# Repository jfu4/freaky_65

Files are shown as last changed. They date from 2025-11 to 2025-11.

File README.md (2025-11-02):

# freaky_65
This is my first mechanical keybaord PCB.

Specifications:
- 65 % Layout
- USB-C
- STM32MCU
- Rotary encoder
- RGB Lighting
- Custom key mapping
- Modular mounting holes

Avatar Fire Nation Build:  


Japanese Black and White Office Build:  


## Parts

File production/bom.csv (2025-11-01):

Designator | Footprint | Quantity | Value | LCSC Part #
BOOT1, RST1 | SW_SPST_TL3342 | 2 | SW_SPST | C318884
C1, C3, C4, C5, C6, C7, C8 | 402 | 7 | 100nF | C1525
C10, C9 | 402 | 2 | 1uF | C52923
C11, C12, C13, C14, C15, C16, C17, C18, C19, C20, C21, C22, C23, C24, C25, C26 | 402 | 16 | 0.1 uF | C1525
C2 | 603 | 1 | 10uF | C15525
D1, D10, D11, D12, D13, D14, D15, D16, D17, D18, D19, D2, D20, D21, D22, D23, D24, D25, D26, D27, D28, D29, D3, D30, D31, D32, D33, D34, D35, D36, D37, D38, D39, D4, D40, D41, D42, D43, D44, D45, D46, D47, D48, D49, D5, D50, D51, D52, D53, D54, D55, D56, D57, D58, D59, D6, D60, D61, D62, D63, D64, D65, D66, D67, D68, D7, D8, D9 | D_SOD-123 | 68 | D_Small | C81598
D69, D70, D71, D72, D73, D74, D75, D76, D77, D78, D79, D80, D81, D82 | LED_WS2812B_PLCC4_5.0x5.0mm_P3.2mm | 14 | WS2812B | C2843785
F1 | 1206 | 1 | 500mA | C135341
J1 | USB_C_Receptacle_HRO_TYPE-C-31-M-12 | 1 | USB_C_Receptacle_USB2.0 | C165948
R1, R2, R3, R4 | 402 | 4 | 5.1k | C25905
R7, R8 | 603 | 2 | 5.1k
SW2 | ROT_Alps_EC11E-Switch | 1 | RotaryEncoder_Switch | C202365
U1 | LQFP-48_7x7mm_P0.5mm | 1 | STM32F072CBT6
U2 | SOT-143 | 1 | PRTR5V0U2X | C2827688
U3 | SOT-23 | 1 | XC6206PxxxMR-Regulator_Linear | C5446
U4 | SOT-363_SC-70-6_Handsoldering | 1 | TXB0101 | C324081

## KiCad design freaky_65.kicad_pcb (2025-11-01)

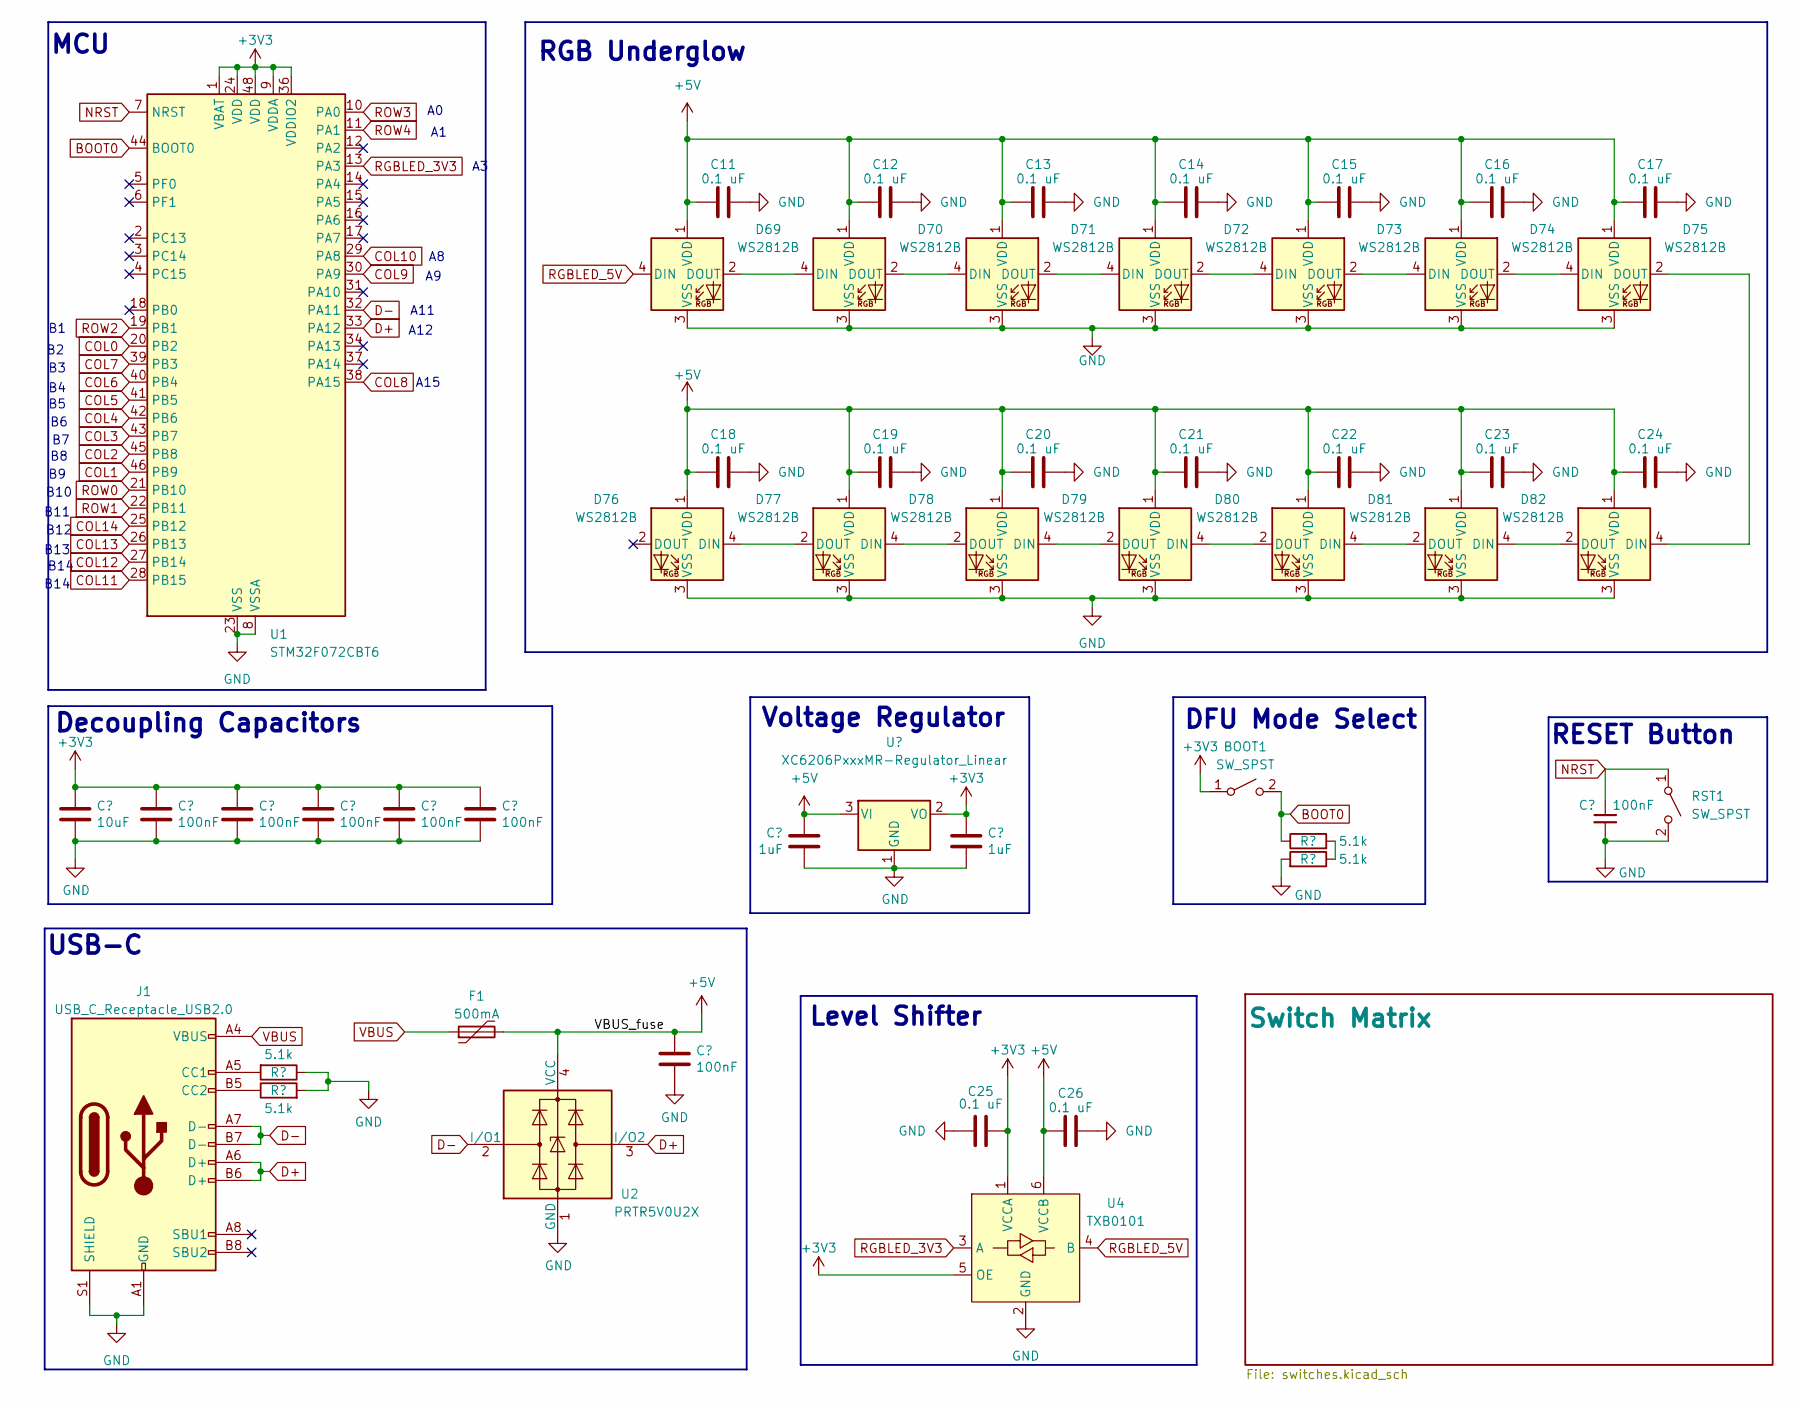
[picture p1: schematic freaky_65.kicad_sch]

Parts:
BOOT1: SW_SPST; SW_SPST_TL3342
C1, C3, C4, C5, C6, C7, C8: 100nF; C_0402_1005Metric; LCSC C307331
C2: 10uF; C_0603_1608Metric; LCSC C307331
C9, C10: 1uF; C_0402_1005Metric; LCSC C307331
C11, C12, C13, C14, C15, C16, C17, C18, C19, C20, C21, C22, C23, C24, C25, C26: 0.1 uF; C_0402_1005Metric_Pad0.74x0.62mm_HandSolder
D69, D70, D71, D72, D73, D74, D75, D76, D77, D78, D79, D80, D81, D82: WS2812B; LED_WS2812B_PLCC4_5.0x5.0mm_P3.2mm
F1: 500mA; Fuse_1206_3216Metric; LCSC C135341
J1: USB_C_Receptacle_USB2.0; USB_C_Receptacle_HRO_TYPE-C-31-M-12; JlcRotOffset 180
R1, R2, R3, R4: 5.1k; R_0402_1005Metric
RST1: SW_SPST; SW_SPST_TL3342
U1: STM32F072CBT6; LQFP-48_7x7mm_P0.5mm; JlcRotOffset 90
U2: PRTR5V0U2X; SOT-143; LCSC C2827688
U3: XC6206PxxxMR-Regulator_Linear; SOT-23; LCSC C5446
U4: TXB0101; SOT-363_SC-70-6_Handsoldering; LCSC C324081

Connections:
+3V3: BOOT1.1 (A), C2.1, C3.1, C4.1, C5.1, C6.1, C7.1, C10.1, C25.1, U1.1 (VBAT), U1.9 (VDDA), U1.24 (VDD), U1.36 (VDDIO2), U1.48 (VDD), U3.2 (VO), U4.1 (VCCA), U4.5 (OE); also elsewhere on the board
+5V: C8.1, C9.1, C11.1, C12.1, C13.1, C14.1, C15.1, C16.1, C17.1, C18.1, C19.1, C20.1, C21.1, C22.1, C23.1, C24.1, C26.1, D69.1 (VDD), D70.1 (VDD), D71.1 (VDD), D72.1 (VDD), D73.1 (VDD), D74.1 (VDD), D75.1 (VDD), D76.1 (VDD), D77.1 (VDD), D78.1 (VDD), D79.1 (VDD), D80.1 (VDD), D81.1 (VDD), D82.1 (VDD), F1.2, U2.4 (VCC), U3.3 (VI), U4.6 (VCCB)
BOOT0: BOOT1.2 (B), R3.1, U1.44 (BOOT0)
COL0: U1.20 (PB2); also elsewhere on the board
COL1: U1.46 (PB9); also elsewhere on the board
COL2: U1.45 (PB8); also elsewhere on the board
COL3: U1.43 (PB7); also elsewhere on the board
COL4: U1.42 (PB6); also elsewhere on the board
COL5: U1.41 (PB5); also elsewhere on the board
COL6: U1.40 (PB4); also elsewhere on the board
COL7: U1.39 (PB3); also elsewhere on the board
COL8: U1.38 (PA15); also elsewhere on the board
COL9: U1.30 (PA9); also elsewhere on the board
COL10: U1.29 (PA8); also elsewhere on the board
COL11: U1.28 (PB15); also elsewhere on the board
COL12: U1.27 (PB14); also elsewhere on the board
COL13: U1.26 (PB13); also elsewhere on the board
COL14: U1.25 (PB12); also elsewhere on the board
D+: J1.A6 (D+), J1.B6 (D+), U1.33 (PA12), U2.3 (I/O2)
D-: J1.A7 (D-), J1.B7 (D-), U1.32 (PA11), U2.2 (I/O1)
GND: C1.2, C2.2, C3.2, C4.2, C5.2, C6.2, C7.2, C8.2, C9.2, C10.2, C11.2, C12.2, C13.2, C14.2, C15.2, C16.2, C17.2, C18.2, C19.2, C20.2, C21.2, C22.2, C23.2, C24.2, C25.2, C26.2, D69.3 (VSS), D70.3 (VSS), D71.3 (VSS), D72.3 (VSS), D73.3 (VSS), D74.3 (VSS), D75.3 (VSS), D76.3 (VSS), D77.3 (VSS), D78.3 (VSS), D79.3 (VSS), D80.3 (VSS), D81.3 (VSS), D82.3 (VSS), J1.A1 (GND), J1.A12 (GND), J1.B1 (GND), J1.B12 (GND), J1.S1 (SHIELD), R1.1, R2.2, R4.2, RST1.2 (B), U1.8 (VSSA), U1.23 (VSS), U1.35 (VSS), U1.47 (VSS), U2.1 (GND), U3.1 (GND), U4.2 (GND); also elsewhere on the board
NRST: C1.1, RST1.1 (A), U1.7 (NRST)
unnamed: D69.2 (DOUT), D70.4 (DIN)
unnamed: D70.2 (DOUT), D71.4 (DIN)
unnamed: D71.2 (DOUT), D72.4 (DIN)
unnamed: D72.2 (DOUT), D73.4 (DIN)
unnamed: D73.2 (DOUT), D74.4 (DIN)
unnamed: D74.2 (DOUT), D75.4 (DIN)
unnamed: D75.2 (DOUT), D82.4 (DIN)
unnamed: D76.4 (DIN), D77.2 (DOUT)
unnamed: D77.4 (DIN), D78.2 (DOUT)
unnamed: D78.4 (DIN), D79.2 (DOUT)
unnamed: D79.4 (DIN), D80.2 (DOUT)
unnamed: D80.4 (DIN), D81.2 (DOUT)
unnamed: D81.4 (DIN), D82.2 (DOUT)
unnamed: J1.A5 (CC1), R1.2
unnamed: J1.B5 (CC2), R2.1
unnamed: R3.2, R4.1
RGBLED_3V3: U1.13 (PA3), U4.3 (A)
RGBLED_5V: D69.4 (DIN), U4.4 (B)
ROW0: U1.21 (PB10); also elsewhere on the board
ROW1: U1.22 (PB11); also elsewhere on the board
ROW2: U1.19 (PB1); also elsewhere on the board
ROW3: U1.10 (PA0); also elsewhere on the board
ROW4: U1.11 (PA1); also elsewhere on the board
VBUS: F1.1, J1.A4 (VBUS), J1.A9 (VBUS), J1.B4 (VBUS), J1.B9 (VBUS)

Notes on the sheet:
USB-C
B13
Level Shifter
DFU Mode Select
B12
MCU
RESET Button
B14
A11
A15
A12
B10
B11
RGB Underglow
Decoupling Capacitors
Voltage Regulator

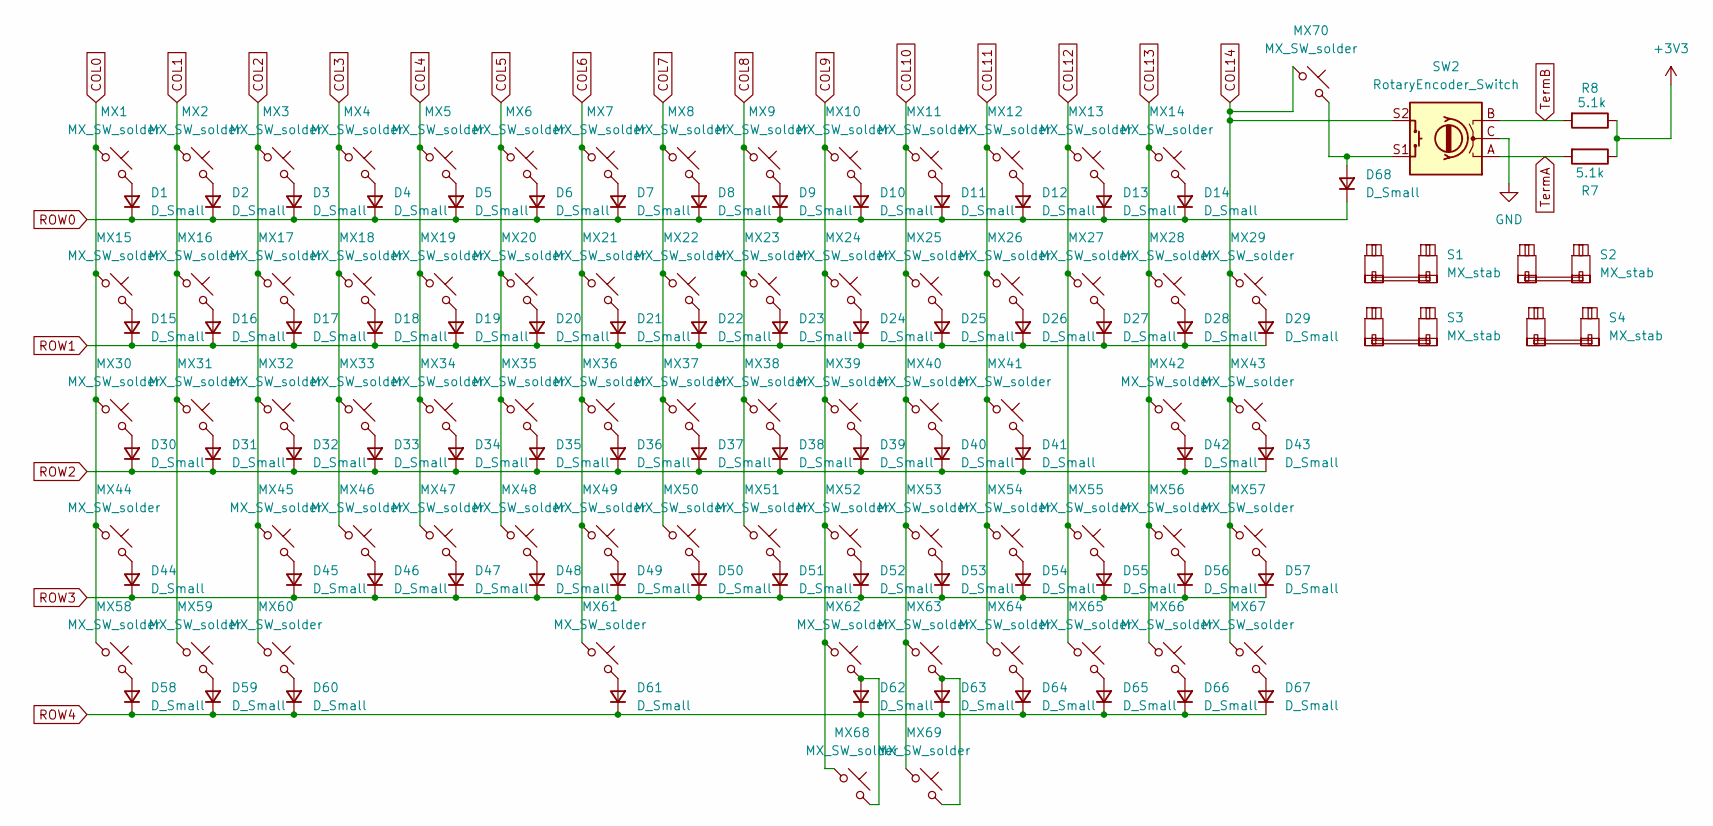
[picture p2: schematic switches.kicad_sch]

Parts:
D1, D2, D3, D4, D5, D6, D7, D8, D9, D10, D11, D12, D13, D14, D15, D16, D17, D18, D19, D20, D21, D22, D23, D24, D25, D26, D27, D28, D29, D30, D31, D32, D33, D34, D35, D36, D37, D38, D39, D40, D41, D42, D43, D44, D45, D46, D47, D48, D49, D50, D51, D52, D53, D54, D55, D56, D57, D58, D59, D60, D61, D62, D63, D64, D65, D66, D67, D68: D_Small; D_SOD-123
MX1, MX2, MX3, MX4, MX5, MX6, MX7, MX8, MX9, MX10, MX11, MX12, MX13, MX14, MX16, MX17, MX18, MX19, MX20, MX21, MX22, MX23, MX24, MX25, MX26, MX27, MX29, MX31, MX32, MX33, MX34, MX35, MX36, MX37, MX38, MX39, MX40, MX41, MX42, MX43, MX44, MX45, MX46, MX47, MX48, MX49, MX50, MX51, MX52, MX53, MX54, MX56, MX57, MX61, MX62, MX63, MX64, MX65, MX66, MX67, MX70: MX_SW_solder; SW_MX_1u
MX15, MX28: MX_SW_solder; SW_MX_1.5u
MX30, MX55: MX_SW_solder; SW_MX_1.75u
MX58, MX59, MX60, MX68, MX69: MX_SW_solder; SW_MX_1.25u
R7, R8: 5.1k; R_0603_1608Metric_Pad0.98x0.95mm_HandSolder
S1: MX_stab; STAB_MX_P_6.25u
S2, S3: MX_stab; STAB_MX_2.25u
S4: MX_stab; STAB_MX_2u
SW2: RotaryEncoder_Switch; ROT_Alps_EC11E-Switch

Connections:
+3V3: R7.1, R8.1; also elsewhere on the board
COL0: MX1.1, MX15.1, MX30.1, MX44.1, MX58.1; also elsewhere on the board
COL1: MX2.1, MX16.1, MX31.1, MX59.1; also elsewhere on the board
COL2: MX3.1, MX17.1, MX32.1, MX45.1, MX60.1; also elsewhere on the board
COL3: MX4.1, MX18.1, MX33.1, MX46.1; also elsewhere on the board
COL4: MX5.1, MX19.1, MX34.1, MX47.1; also elsewhere on the board
COL5: MX6.1, MX20.1, MX35.1, MX48.1; also elsewhere on the board
COL6: MX7.1, MX21.1, MX36.1, MX49.1, MX61.1; also elsewhere on the board
COL7: MX8.1, MX22.1, MX37.1, MX50.1; also elsewhere on the board
COL8: MX9.1, MX23.1, MX38.1, MX51.1; also elsewhere on the board
COL9: MX10.1, MX24.1, MX39.1, MX52.1, MX62.1, MX68.1; also elsewhere on the board
COL10: MX11.1, MX25.1, MX40.1, MX53.1, MX63.1, MX69.1; also elsewhere on the board
COL11: MX12.1, MX26.1, MX41.1, MX54.1, MX64.1; also elsewhere on the board
COL12: MX13.1, MX27.1, MX55.1, MX65.1; also elsewhere on the board
COL13: MX14.1, MX28.1, MX42.1, MX56.1, MX66.1; also elsewhere on the board
COL14: MX29.1, MX43.1, MX57.1, MX67.1, MX70.1, SW2.S2; also elsewhere on the board
GND: SW2.C; also elsewhere on the board
unnamed: D1.2 (A), MX1.2
unnamed: D2.2 (A), MX2.2
unnamed: D3.2 (A), MX3.2
unnamed: D4.2 (A), MX4.2
unnamed: D5.2 (A), MX5.2
unnamed: D6.2 (A), MX6.2
unnamed: D7.2 (A), MX7.2
unnamed: D8.2 (A), MX8.2
unnamed: D9.2 (A), MX9.2
unnamed: D10.2 (A), MX10.2
unnamed: D11.2 (A), MX11.2
unnamed: D12.2 (A), MX12.2
unnamed: D13.2 (A), MX13.2
unnamed: D14.2 (A), MX14.2
unnamed: D15.2 (A), MX15.2
unnamed: D16.2 (A), MX16.2
unnamed: D17.2 (A), MX17.2
unnamed: D18.2 (A), MX18.2
unnamed: D19.2 (A), MX19.2
unnamed: D20.2 (A), MX20.2
unnamed: D21.2 (A), MX21.2
unnamed: D22.2 (A), MX22.2
unnamed: D23.2 (A), MX23.2
unnamed: D24.2 (A), MX24.2
unnamed: D25.2 (A), MX25.2
unnamed: D26.2 (A), MX26.2
unnamed: D27.2 (A), MX27.2
unnamed: D28.2 (A), MX28.2
unnamed: D29.2 (A), MX29.2
unnamed: D30.2 (A), MX30.2
unnamed: D31.2 (A), MX31.2
unnamed: D32.2 (A), MX32.2
unnamed: D33.2 (A), MX33.2
unnamed: D34.2 (A), MX34.2
unnamed: D35.2 (A), MX35.2
unnamed: D36.2 (A), MX36.2
unnamed: D37.2 (A), MX37.2
unnamed: D38.2 (A), MX38.2
unnamed: D39.2 (A), MX39.2
unnamed: D40.2 (A), MX40.2
unnamed: D41.2 (A), MX41.2
unnamed: D42.2 (A), MX42.2
unnamed: D43.2 (A), MX43.2
unnamed: D44.2 (A), MX44.2
unnamed: D45.2 (A), MX45.2
unnamed: D46.2 (A), MX46.2
unnamed: D47.2 (A), MX47.2
unnamed: D48.2 (A), MX48.2
unnamed: D49.2 (A), MX49.2
unnamed: D50.2 (A), MX50.2
unnamed: D51.2 (A), MX51.2
unnamed: D52.2 (A), MX52.2
unnamed: D53.2 (A), MX53.2
unnamed: D54.2 (A), MX54.2
unnamed: D55.2 (A), MX55.2
unnamed: D56.2 (A), MX56.2
unnamed: D57.2 (A), MX57.2
unnamed: D58.2 (A), MX58.2
unnamed: D59.2 (A), MX59.2
unnamed: D60.2 (A), MX60.2
unnamed: D61.2 (A), MX61.2
unnamed: D62.2 (A), MX62.2, MX68.2
unnamed: D63.2 (A), MX63.2, MX69.2
unnamed: D64.2 (A), MX64.2
unnamed: D65.2 (A), MX65.2
unnamed: D66.2 (A), MX66.2
unnamed: D67.2 (A), MX67.2
unnamed: D68.2 (A), MX70.2, SW2.S1
ROW0: D1.1 (K), D2.1 (K), D3.1 (K), D4.1 (K), D5.1 (K), D6.1 (K), D7.1 (K), D8.1 (K), D9.1 (K), D10.1 (K), D11.1 (K), D12.1 (K), D13.1 (K), D14.1 (K), D68.1 (K); also elsewhere on the board
ROW1: D15.1 (K), D16.1 (K), D17.1 (K), D18.1 (K), D19.1 (K), D20.1 (K), D21.1 (K), D22.1 (K), D23.1 (K), D24.1 (K), D25.1 (K), D26.1 (K), D27.1 (K), D28.1 (K), D29.1 (K); also elsewhere on the board
ROW2: D30.1 (K), D31.1 (K), D32.1 (K), D33.1 (K), D34.1 (K), D35.1 (K), D36.1 (K), D37.1 (K), D38.1 (K), D39.1 (K), D40.1 (K), D41.1 (K), D42.1 (K), D43.1 (K); also elsewhere on the board
ROW3: D44.1 (K), D45.1 (K), D46.1 (K), D47.1 (K), D48.1 (K), D49.1 (K), D50.1 (K), D51.1 (K), D52.1 (K), D53.1 (K), D54.1 (K), D55.1 (K), D56.1 (K), D57.1 (K); also elsewhere on the board
ROW4: D58.1 (K), D59.1 (K), D60.1 (K), D61.1 (K), D62.1 (K), D63.1 (K), D64.1 (K), D65.1 (K), D66.1 (K), D67.1 (K); also elsewhere on the board
TermA: R7.2, SW2.A
TermB: R8.2, SW2.B

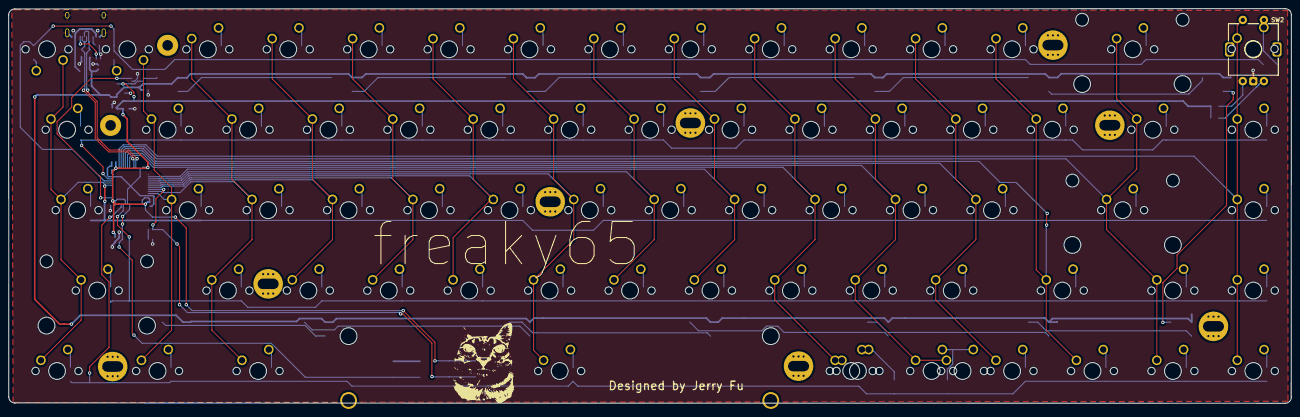
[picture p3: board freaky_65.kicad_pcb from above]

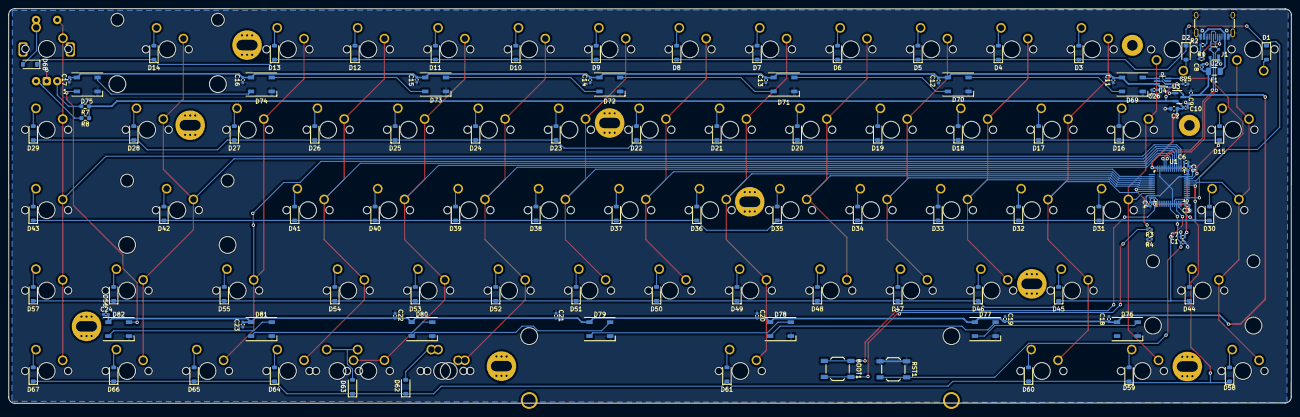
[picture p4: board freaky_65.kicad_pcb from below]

Board: 2 copper layers, 303.8 x 93.5 mm, 197 parts (122 on the bottom side), 116 nets.

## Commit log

2025-11-01 Initial commit of existing KiCad project
    [bom.csv, bom_jlcparts.csv, designators.csv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]
2025-11-02 Initial commit (reset repo)
    [freaky_65.kicad_pcb, freaky_65.kicad_sch, switches.kicad_sch]
